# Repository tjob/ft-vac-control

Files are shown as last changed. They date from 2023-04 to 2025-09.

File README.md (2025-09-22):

# Use a Festool Bluetooth remote control with any vacuum

Use the Festool Bluetooth remote with vacuum extractors from other manufacturers.

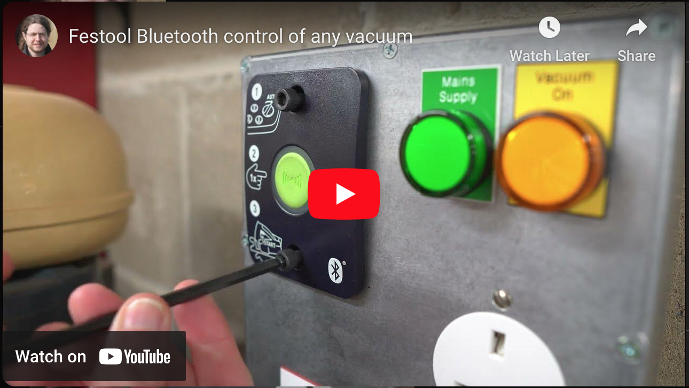
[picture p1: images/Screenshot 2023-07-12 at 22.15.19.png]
Video Demo (https://youtu.be/SCtY6I_2gwY)


The project contains the schematics and PCB layout designed using [KiCad 7](https://www.kicad.org/), and the firmware (written in C) for the [Raspberry Pi Pico](https://www.raspberrypi.com/products/raspberry-pi-pico/) to interface with a [Festool No. 202097 Bluetooth Remote Control add-on](https://www.amazon.co.uk/Festool-202097-Remote-Control-Blue/dp/B0794ZWFLR).

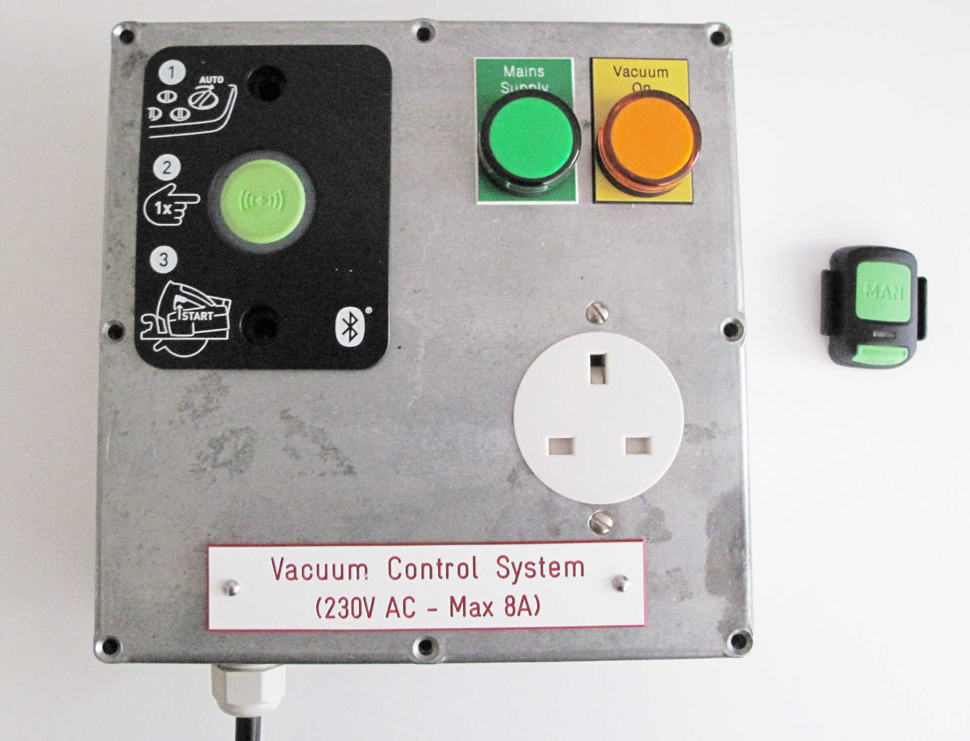
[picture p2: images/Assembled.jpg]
Assembled project


Festool sell an upgrade for their CT26/36/48 vacuum extractors to give remote control using Bluetooth, CT-F I/M-Set. It has two parts: the "CT-F I/M" installs in the extractor and the "CT-F I" is the button that attaches to the end of the vacuum hose. The button then starts and stops the extractor. Paired cordless tools with their Bluetooth-enabled batteries can also control the extractor.

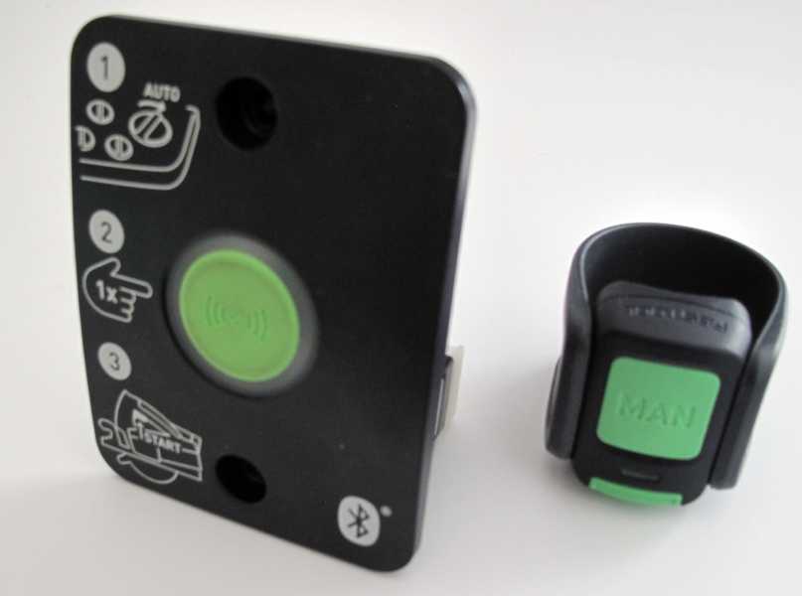
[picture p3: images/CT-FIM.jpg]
Festool's bluetooth kit


But I don't have a CT26/36/48 extractor from Festool, so I wanted to create an adaptor that uses the module and controls a standard power socket to control any device attached. With a custom PCB, a Raspberry Pi Pico, some firmware, a Solid State Relay, and an enclosure I had a working solution.  Along the way I had to reverse-engineer the non-standard serial protocol and try to make sense of the bytes sent.

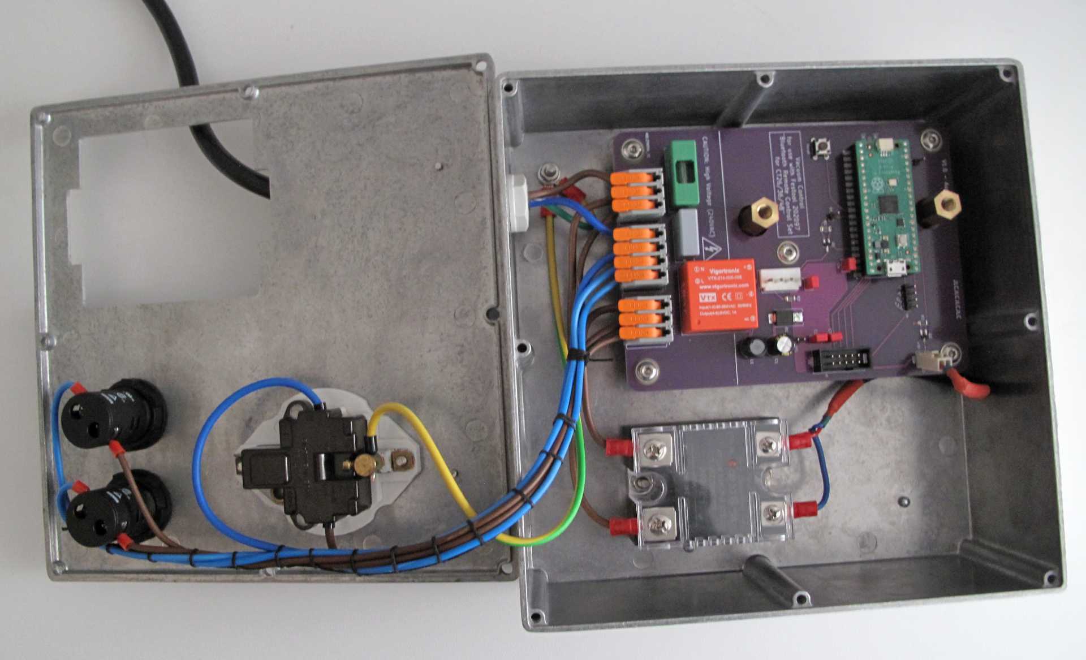
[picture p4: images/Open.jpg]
Inside the box


## Features
 - Allows connecting any vacuum extractor that has a physical switch capable of being always on. A vacuum with an NVR will not work.
 - Works with an unmodified Festool No. 202097 receiver. It's Plug and Play. At a later date if I ever get a CT extractor I wanted to be able to use this module again.
 - Has software safety features: automatically turns off if left on for an extended period. Uses the RP2040's hardware watchdog to shut off the power if the software stops for any reason.
 - Should work with Festool cordless tools with their Bluetooth batteries (untested). 

## How it works
The Festool module has three electrical connections to the host vacuum: two for power and one for data. The data line is serial, probably bidirectional, and uses a form of Manchester encoding. For more details on the serial stream and commands, see the [description of the traces](./software/traces/) captured with a logic analyzer.

Decoded serial steam

The serial data from the receiver feeds the Raspberry Pi Pico via a BSS138 MOSFET as a level shifter. The Pico decodes the Manchester-encoded stream. When the Start/Stop commands are seen the software switches a Solid State Relay controlling mains AC supply to the output socket.

Wanting an excuse to learn KiCad, I designed a custom PCB to host the Pi Pico and a 4-pin 3.96 mm header to plug the CT-F I/M Bluetooth module into. The board contains a 240V switch-mode regulator providing 5V DC power to both the Pico and the CT-F I/M.

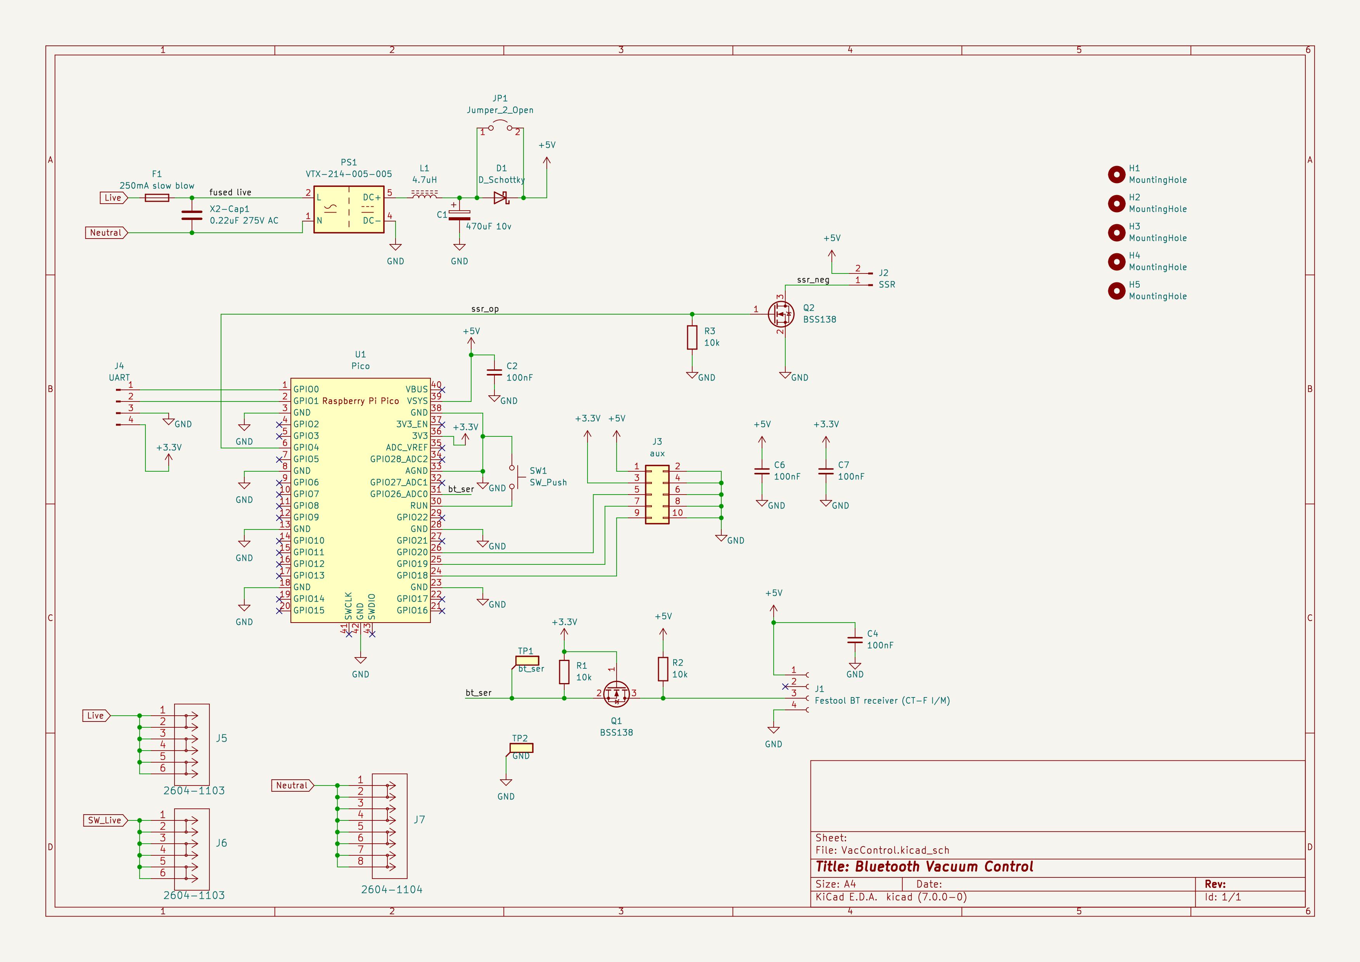
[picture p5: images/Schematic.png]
Circuit schematic diagram


## :zap: Mains voltage electricity can kill! :zap: 

> [!WARNING] 
> This project description is not a guide and does not detail how to assemble a unit safely.  If you are not sure how to build one that is safe and complies with local laws and regulations, DO NOT ATTEMPT TO RECREATE.

## Bill of Materials

Parts on the PCB
| Part | Reference Designator | Description |
| ---- | --- | --- |
| MCU | U1 | Raspberry Pi Pico, [the cheap one](https://thepihut.com/products/raspberry-pi-pico?variant=41925332533443)|
| 5V PCB mount PSU | PS1 | [Vigortronix VTX-214-005-005 5W Miniature SMPS AC-DC Converter 5V Output](https://www.rapidonline.com/vigortronix-vtx-214-005-005-5w-miniature-smps-ac-dc-converter-5v-output-84-2731) |
| Fuse holder | F1 | [5.2x20mm PCB Fuse Holder W/Cover 6.3A 250VAC](https://www.switchelectronics.co.uk/products/5-2x20mm-pcb-fuse-holder-w-cover-6-3a-250vac) |
| PSU protection diode | D1 | Optional, diode to stop power from USB flowing back into the PSU. If not installed, bridge JP2 instead |
| RX data port | J1 | Connects to the Festool receiver module. 4 pin, 3.96mm pitch header with plastic tab cut off - e.g. [JST B4P-VH(LF)(SN)](https://www.rapidonline.com/jst-b4p-vh-lf-sn-4-pole-top-entry-vh-series-p3-96-mm-22-5294) |
| SSR driver header | J2 | 2 way, 2.54mm board-to-wire header for connecting to the input of the SSR |
| Wago 3 way PCB connector | J5, J6 |Wago part number 2604-1103 |
| Wago 4 way PCB connector | J7 | Wago part number 2604-1104 |
| Signal MOSFETs | Q1,  Q2| BSS138, in SOT-23 package |
| 10k Resistors | R1, R2, R3 | SMT 1206 package  |
| 4.7uH | L1 | Inductor, [RLB0913-4R7K](https://uk.farnell.com/bourns/rlb0913-4r7k/inductor-4-7uh-4a-10-radial/dp/2725243) |
| 100nF | C2, C4, C6, C7 | Decoupling capacitors, through-hole, 2.5mm pitch | 
| 470uF 10V | C1 | [Suntan TS13DJ1A471MSB040R 470uf 10V Low Imp Electrolytic Capacitor](https://www.rapidonline.com/suntan-ts13dj1a471msb040r-470uf-10v-low-imp-electrolytic-capacitor-11-3664) |
| X2 Capacitor | X2-Cap1 | [Vishay BFC2-336-20224 220n 275V X2 Suppression Capacitor](https://www.rapidonline.com/vishay-bfc2-336-20224-220n-275v-x2-suppression-capacitor-10-2680)|
| Debug UART | J4 |  Optional (usefully only for firmware development) |
| Test points | TP1, TP2 | Optional, do not populate |
| Aux port | J3 | Optional and currently unused |
| Reset switch | SW1 | Optional (usefully only for firmware development) |

Other mechanical and electrical parts 

| Parts | Count | Description |
| ----- | ----- | --- |
| Enclosure | 1 | 190mm x 190mm x 67mm die-cast aluminum box  |
| Mains plug + inlet cable | 1 | I used a molded plug on a cable cut from an IEC lead |
| Power in strain relief | 1 | Cable Gland M16 10mm - e.g. [50616PA7001SET](https://cpc.farnell.com/hylec/50616pa7001set/nylon-m16-cable-gland-grey/dp/CBBR4095) |
| Output socket | 1 | 13A Circular Panel Mount Socket Outlet, 13A - e.g. [735WHI](https://cpc.farnell.com/mk/735whi/1-gang-outlet-panel-mount/dp/PL00703)
| Green indicator | 1 | Panel mount, 22.5mm, 220-240v, to show if the incoming power is on - e.g. [LEDTECGREEN230VAC](https://www.rapidonline.com/techna-ledtecgreen230vac-led-pilot-light-green-220-240vac-28-5357) |
| Yellow indicator | 1 | Panel mount, 22.5mm, 220-240v, LED lamp, to show if the vacuum power is on - e.g. [LEDTECYELLOW230VAC](https://www.rapidonline.com/techna-ledtecyellow230vac-led-pilot-light-yellow-amber-220-240vac-28-5369) |
|PCB standoffs | 5 | M4 - length dependent on the enclosure used |
| M6 x 35mm cap screws | 2 | Black, for securing the Festool receiver module |
| Custom M6 standoffs | 2 | To receive the M6 screws from the Festool receiver module. Length depends on the enclosure used, 39.1mm was correct for me |
| PCB screws | 5 | M4 x 8mm |
| SSR | 1 | Random on Solid State Relay, must be switchable by 5V DC - e.g. [i-Autoc Panel Mount Solid State Relay, 25 A Max. Load, 280V AC](https://uk.rs-online.com/web/p/solid-state-relays/1640576) |
| SSR cover | 1 | [i-Autoc Kudom KPC-0A Solid State Relay Accessory Protective Cover Single Phase](https://www.rapidonline.com/i-autoc-kudom-kpc-0a-solid-state-relay-accessory-protective-cover-single-phase-60-1586) |
| SSR thermal pad | 1 |[i-Autoc Kudom KTP-0A Solid State Relay Accessory Thermal Pad KSI/KSJ](https://www.rapidonline.com/i-autoc-kudom-ktp-0a-solid-state-relay-accessory-thermal-pad-ksi-ksj-60-1587) |
| Mains wiring loom | Assorted | Line, Neutral, Earth (CPC), sided appropriately for your max load. I used stranded 2.5mm<sup>2</sup> |
| Bits 'n' Bobs | Assorted | Hardware to attach standoffs to enclosure and to mount the SSR, earth bonding nuts and bolds, and crimp eyelets and spade connectors |

## License
The software, schematic designs and PCB layout contained in this repository are released under the MIT license.

## Credits
I got the pinout for the Bluetooth receiver from YouTube channel "My Project Box". His video ["Festool Bluetooth Hack / Mod works with any dust extractor!"](https://www.youtube.com/watch?v=EyrakKOR5tI) shows a very neat solution with a different approach; avoiding any software.

On Github, user gilbertf published [libft](https://github.com/gilbertf/libft) capable of both sending and receiving. It's not used by this project but his encoder appears to send the same bytes my decoder expects, which gave me some confidence that the implementation here is somewhat interoperable.

I used the Pi Pico KiCAD symbol and footprint from [ncarandini/KiCad-RP-Pico](https://github.com/ncarandini/KiCad-RP-Pico)

## Other projects inspired by this one
This project helped [Loriowar](https://github.com/Loriowar) create a [Festool receiver handler](https://github.com/Loriowar/festool_ct-f_im_handler) for Arduino.

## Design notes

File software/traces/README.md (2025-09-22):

# Serial signal traces

These traces (.sr files) capture the output signal of the Festool CT-F I/M Bluetooth module when not connected to a CT vacuum extractor.  They can be viewed using [Pulseview](https://sigrok.org/wiki/PulseView) from the sigrok project.

## Power on reset [(Startup.sr)](Startup.sr)
Approximately 590 ms after power on, the Bluetooth module sends a single 1 byte message of `0x1d` to the extractor.  Its function is unknown.

## Manual remote on [(On.sr)](On.sr)
When the Bluetooth module receives the first (and all other odd numbered) press of the manual remote (CT-F I) button the module sends 3 separate messages to the extractor. Each is two bytes long.

```
Message 1:
0x0117 (2 bytes)  // Turn extractor on command
[Delay of ~284 ms]

Message 2:
0xff23 (2 bytes)  // Extractor at full speed?
[Delay of ~387 ms]

Message 3:
0x0117 (2 bytes)  // Repeated turn on command
```

Assumptions: The first and last messages are the ON command, not clear why it's repeated (maybe because the extractor did not reply?).  The middle message sets the extractor speed.

## Manual remote off [(Off.sr)](Off.sr)

For the second press of the manual (CT-F I) remote, and all subsequent even numbered presses, the Bluetooth module sends 4 separate messages to the extractor.

```
Message 1:
0xac17   (2 bytes)  // Turn extractor off command
[Delay of ~11.7 ms]

Message 2:
0x000123 (3 bytes)  // Reduce speed, with rate?
[Delay of ~277 ms]

Message 3:
0x00a0   (2 bytes)  // Unknown?
[Delay of ~689 ms]

Message 4:
0x0023   (2 bytes)  // Reduce speed to zero?
```

Assumptions: The first message is the OFF command. The second and fourth messages are to reduce the speed to zero. The function of the third message is not obvious.

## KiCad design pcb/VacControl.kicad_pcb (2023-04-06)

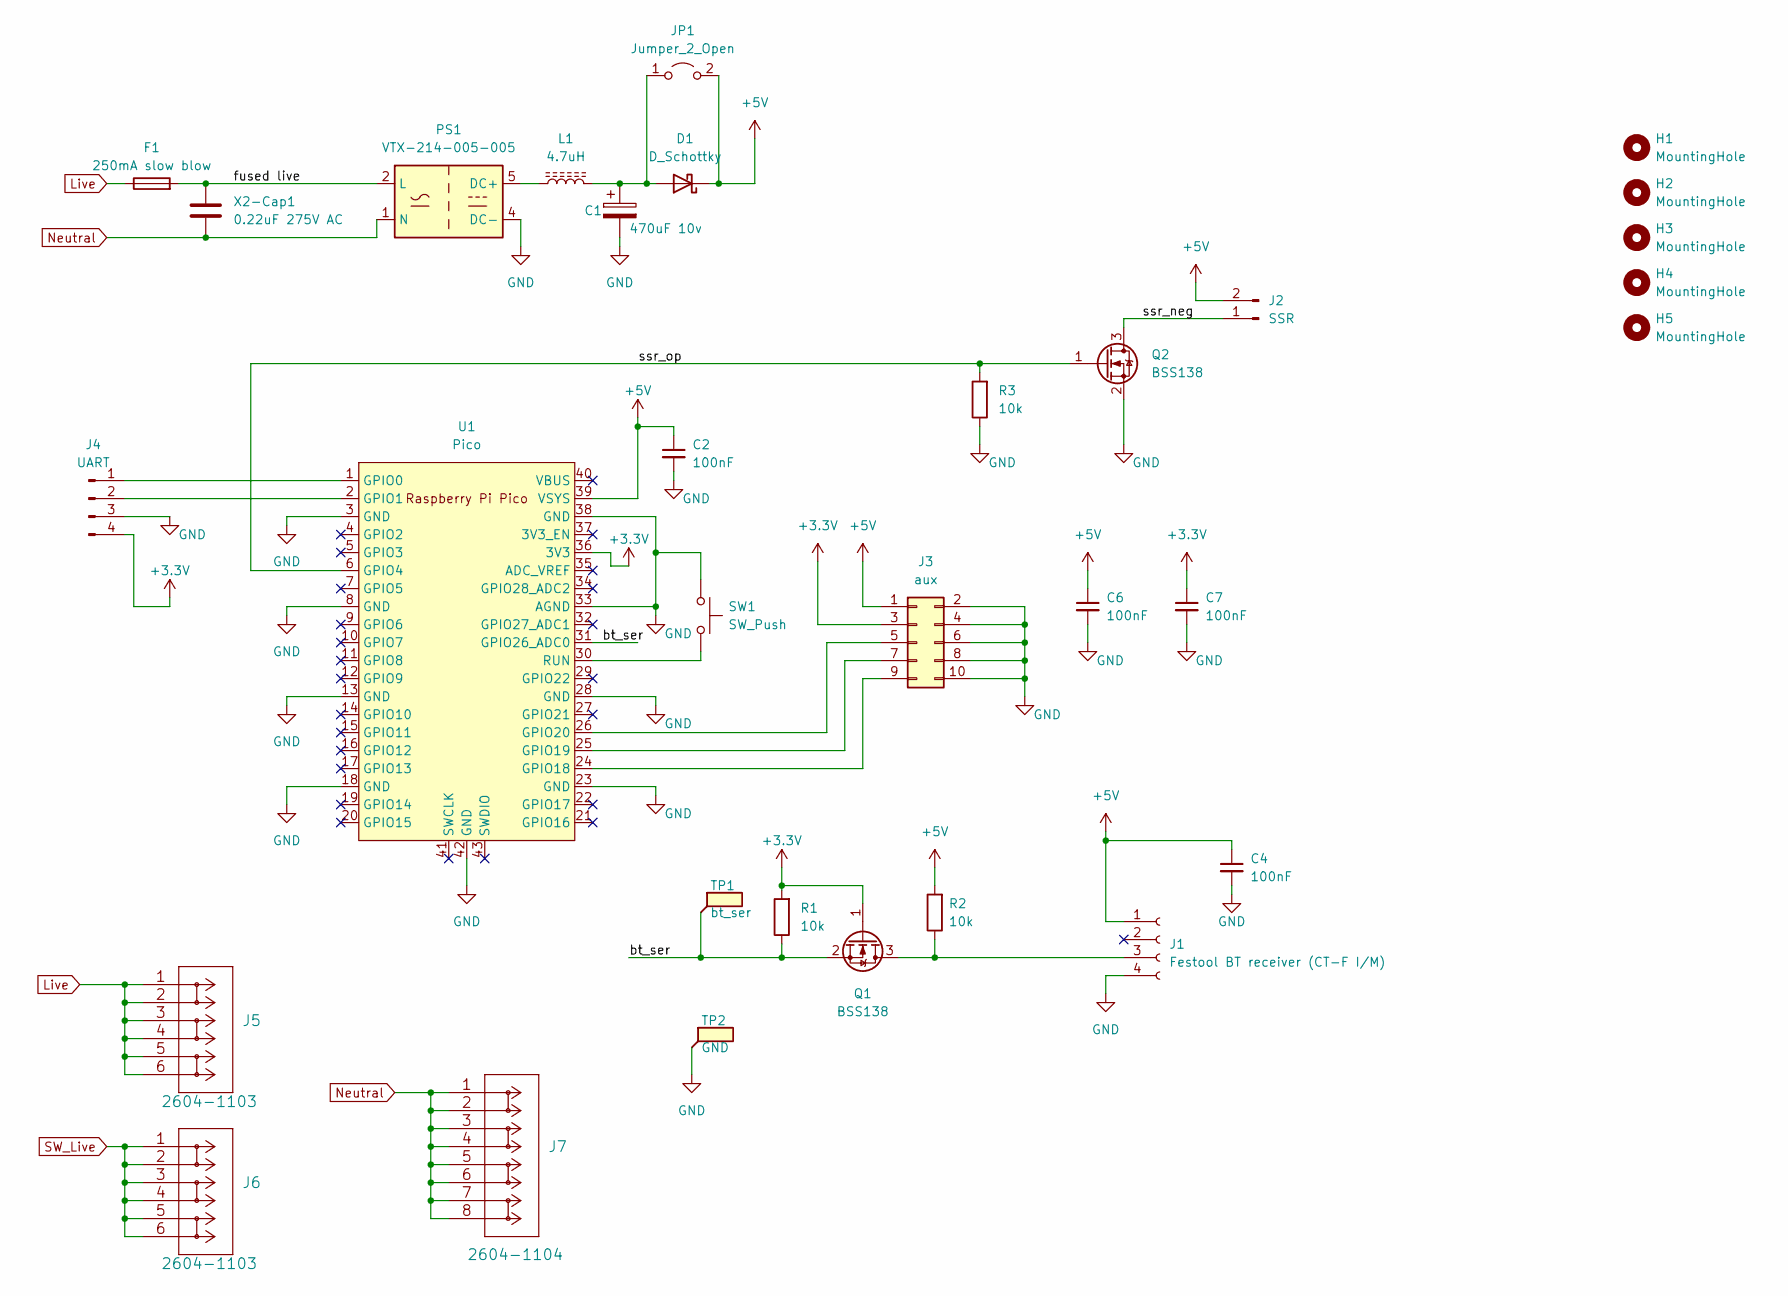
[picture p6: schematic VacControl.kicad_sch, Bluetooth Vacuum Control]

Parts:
C1: 470uF 10v; CP_Radial_D8.0mm_P3.50mm
C2, C4, C6, C7: 100nF; C_Rect_L4.6mm_W3.0mm_P2.50mm_MKS02_FKP02
D1: D_Schottky; D_SMC_Handsoldering
F1: 250mA slow blow; Fuseholder_Cylinder-5x20mm_Stelvio-Kontek_PTF78_Horizontal_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
H1, H2, H3, H4, H5: MountingHole; MountingHole_4.3mm_M4
J1: Festool BT receiver (CT-F I/M); BT receiver
J2: SSR; Molex_KK-254_AE-6410-02A_1x02_P2.54mm_Vertical
J3: aux; IDC-Header_2x05_P2.54mm_Vertical
J4: UART; PinSocket_1x04_P2.54mm_Vertical
J5, J6: 2604-1103
J7: 2604-1104
JP1: Jumper_2_Open; TestPoint_2Pads_Pitch2.54mm_Drill0.8mm
L1: 4.7uH; L_Radial_D7.8mm_P5.00mm_Fastron_07HCP
PS1: VTX-214-005-005; Converter_ACDC_Vigortronix_VTX-214-005-0xx_THT
Q1, Q2: BSS138; SOT-23_Handsoldering
R1, R2, R3: 10k; R_1206_3216Metric_Pad1.30x1.75mm_HandSolder
SW1: SW_Push; SW_PUSH_6mm_H4.3mm
TP1: bt_ser; Pin_D0.9mm_L10.0mm_W2.4mm_FlatFork
TP2: GND; Pin_D0.9mm_L10.0mm_W2.4mm_FlatFork
U1: Pico; RPi_Pico_SMD_TH
X2-Cap1: 0.22uF 275V AC; C_Rect_L18.0mm_W7.0mm_P15.00mm_FKS3_FKP3

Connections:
+3.3V: C7.1, J3.3, J4.4, Q1.1 (G), R1.2, U1.36 (3V3)
+5V: C2.1, C4.1, C6.1, D1.1 (K), J1.1, J2.2, J3.1, JP1.2 (B), R2.2, U1.39 (VSYS)
/bt_ser: Q1.2 (S), R1.1, TP1.1, U1.31 (GPIO26_ADC0)
/fused live: F1.2, PS1.2 (L), X2-Cap1.1
/ssr_neg: J2.1, Q2.3 (D)
/ssr_op: Q2.1 (G), R3.2, U1.6 (GPIO4)
GND: C1.2, C2.2, C4.2, C6.2, C7.2, J1.4, J3.2, J3.4, J3.6, J3.8, J3.10, J4.3, PS1.4 (DC-), Q2.2 (S), R3.1, SW1.1, TP2.1, U1.3 (GND), U1.8 (GND), U1.13 (GND), U1.18 (GND), U1.23 (GND), U1.28 (GND), U1.33 (AGND), U1.38 (GND), U1.42 (GND)
Live: F1.1, J5.1, J5.2, J5.3, J5.4, J5.5, J5.6
unnamed: C1.1, D1.2 (A), JP1.1 (A), L1.2
unnamed: J1.3, Q1.3 (D), R2.1
unnamed: J3.5, U1.26 (GPIO20)
unnamed: J3.7, U1.25 (GPIO19)
unnamed: J3.9, U1.24 (GPIO18)
unnamed: J4.1, U1.1 (GPIO0)
unnamed: J4.2, U1.2 (GPIO1)
unnamed: L1.1, PS1.5 (DC+)
unnamed: SW1.2, U1.30 (RUN)
Neutral: J7.1, J7.2, J7.3, J7.4, J7.5, J7.6, J7.7, J7.8, PS1.1 (N), X2-Cap1.2
SW_Live: J6.1, J6.2, J6.3, J6.4, J6.5, J6.6

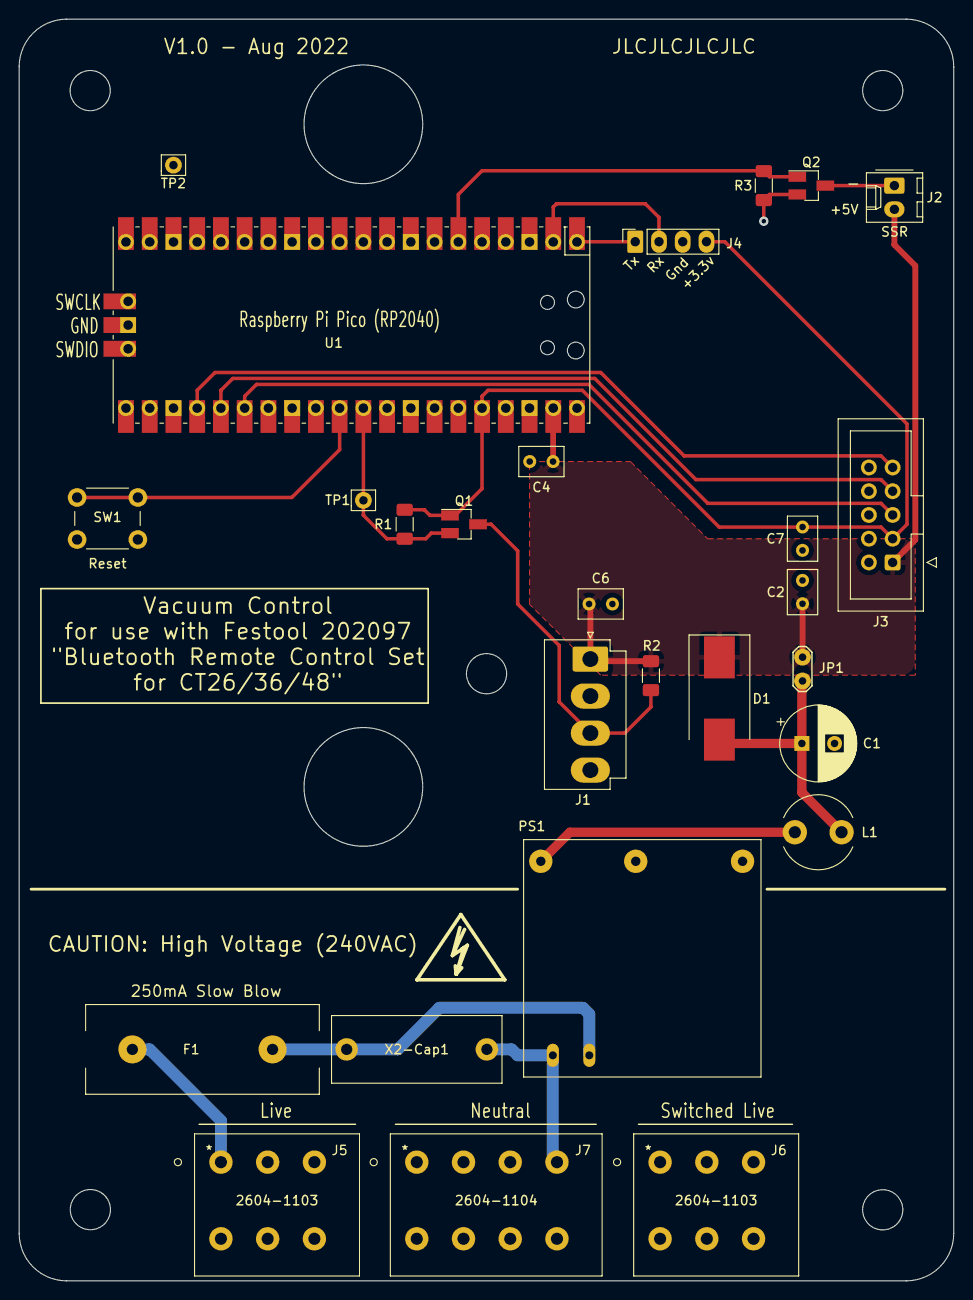
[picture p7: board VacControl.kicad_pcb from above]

Board: 2 copper layers, 100.0 x 135.0 mm, 33 parts (0 on the bottom side), 19 nets.

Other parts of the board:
CAUTION: High Voltage (240VAC): Warning; Symbol_HighVoltage_Type2_CopperTop_VerySmall

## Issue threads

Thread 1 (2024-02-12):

Mention Adruino alternative in the Readme

Loriowar, 2024-02-12:
Hi! Thanks for your project. It helps me to build my own implementation of [Festool receiver handler](https://github.com/Loriowar/festool_ct-f_im_handler). It's built on Arduino Nano and for some people might be even simpler in the implementation in compare with Pico. If you decide this is worth you can add the mention of the [Arduino alternative](https://github.com/Loriowar/festool_ct-f_im_handler) in the Readme.

tjob, 2024-12-02:
Glad you found this helpful,  I added a link to your repo.

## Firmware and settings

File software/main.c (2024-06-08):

/**
 * @file main.c
 * @author tjob
 * @brief Use a Raspberry Pi Pico and a "Festool 202097 CT-F I/M" to control any vacuum extractor.
 * @version 0.1
 * @date 2023-04-02
 * 
 * @copyright Copyright (c) 2023
 * 
 * Uses one GPIO pin, as an input, to read the serial data line from the 
 * Festool Bluetooth receiver. Another GPIO pin, as an output, is used to turn 
 * on/off a relay controlling power to the vacuum extractor.
 */
#include "pico/stdlib.h"
#include "hardware/watchdog.h"
#include <stdio.h>
#include <time.h>
#include "decoder.h"

int main() {
    const uint32_t AUTO_OFF_AFTER = 20*60*1000; ///< Automatically turn off the vacuum if left on for more than 20 minutes.
    const uint FTBT_PIN = 26;   ///< GPIO pin connected to the Festool CT-F I/M Bluetooth receiver module. 
    const uint SSR_PIN = 4;     ///< GPIO pin connected to the Solid State Relay

    decoder_t decoder = {0};            ///< The one and only decoder
    absolute_time_t autoOffTime = {0};  ///< Used to track the absolute time we should automatically turn off if left on.
    uint32_t ticksObserved = 0;         ///< Used to check the decoder is still ticking for the hardware watchdog.
    msg_t message = {0};                ///< Holds a message de-queued from the decoder's FIFO. 

    stdio_init_all();

    if (watchdog_caused_reboot()) {
        printf("Rebooted by watchdog!\n");
    }

    // Setup onboard LED on the Pi Pico as an output. 
    gpio_init(PICO_DEFAULT_LED_PIN);
    gpio_set_dir(PICO_DEFAULT_LED_PIN, GPIO_OUT);

    // Setup the input pin to read the serial line-code from the bluetooth adaptor.
    gpio_init(FTBT_PIN);
    gpio_set_dir(FTBT_PIN, GPIO_IN);

    // Setup the output pin to drive the Solid State Relay controlling the power to the vacuum. 
    gpio_init(SSR_PIN);
    gpio_set_dir(SSR_PIN, GPIO_OUT);
    gpio_put(SSR_PIN, false);   // Default relay output to off at startup.

    // Setup the decoder
    initDecoder(&decoder, FTBT_PIN);
    startDecoder(&decoder);

    // Enable the HW watchdog timer. Needs servicing at least ever 300ms to avoid a hardware reset.
    watchdog_enable(300, true);

    // Main loop.  Never ends, only way out is power down or watchdog reset.
    while (true) {
        // Blink the onboard led as a sign of life.
        gpio_put(PICO_DEFAULT_LED_PIN, time_us_32() & (1 << 19));

        // Delay long enough for the Decoder's timer to have ran at least once
        sleep_ms(10);

        // Only service the watchdog if both the decoder timer and this main loop
        // are running.  If either stops, for any reason, watchdog will reset the 
        // hardware for us.
        if (ticksObserved != decoder.totalTicks) {
            watchdog_update();
            ticksObserved = decoder.totalTicks;
        }

        // Consume all messages from the decoder waiting in the fifo.
        while (queue_try_remove(&decoder.messageFIFO, &message)) {
            // Print the message
            printf("0x%08lx  %d\n", message.data, message.bitsRecieved);

            // Is it a start command?
            if (message.data == (CMD_POWER | CMD_ON)) {
                // Turn on the relay output
                gpio_put(SSR_PIN, true);

                // Safety feature: Calculate the time we should turn off automatically if we need to.
                autoOffTime = make_timeout_time_ms(AUTO_OFF_AFTER);
            }

            // Is it a stop command?
            if (message.data == (CMD_POWER | CMD_OFF)) {
                // Turn off the relay output
                gpio_put(SSR_PIN, false);
            }

            // All other commands are ignored for now.
        }

        // Safety feature: Automatically turn off the vacuum if it's been on too long. 
        if (AUTO_OFF_AFTER && time_reached(autoOffTime)) {
            gpio_put(SSR_PIN, false);
        }
    }

    // Should never get here! Halt.
    stopDecoder(&decoder);
    while (true) {}
    
    return 0;
}

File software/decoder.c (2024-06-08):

/**
 * @file decoder.c
 * @author tjob
 * @brief Decoder serial stream coming from Festool No. 202097 CT-F I/M
 * @version 0.1
 * @date 2023-04-02
 * 
 * @copyright Copyright (c) 2023
 * 
 * The Festool 202097 CT-F I/M Bluetooth add-on for CT26/36/48 vacuum extractors 
 * has 3 electrical connections to the host vacuum; GND, +5V, and Data. The 
 * data line is used for serial communication and runs at approximately 1 kHz. 
 * The Bluetooth receiver encodes bits onto the data line using a form of 
 * Manchester encoding. Line transitions from high to low represent a 1, and 
 * transitions from low to high represent a 0. The line idles high when nothing 
 * is being sent. Messages start with a "break", pulling the line low for 
 * approximately 2 bit periods (2 ms), followed by a "mark" of 1 ms.  There is 
 * a start bit, always 0, followed by several bytes of data. Bytes are sent 
 * least significant bit first.
 * 
 * This decoder receives and decodes the incoming serial stream into messages
 * up to 32bits in length (4 bytes). We define a message to be the bit sequence
 * after the start bit until the line goes idle again. All messages seen so far
 * are an integer number of bytes long. A single press of the manual remote 
 * button results in multiple messages being sent, with a relatively long delay 
 * (100's of ms) between then.
 * 
 * Note: While this decoder works, it's based on observations of one receiver 
 * and one manual remote button. It has not been tested with any of the Festool 
 * cordless Bluetooth battery tools. It is suspected that the serial interface 
 * is bi-directional, allowing the vacuum extractor to respond to the commands. 
 * This implementation is receive only.
 * 
 * Theory of operation:
 * on_16x_timer() runs, ticks from a hardware timer, at approximately 16 times 
 * bit rate. Based on the current state, how long we have been in that state, and
 * how long it's been since the last edge was seen we can decode the signal.
 * The timer is free running but the state machine within synchronizes to the
 * edges seen on the serial input. This takes care of any drift. 
 * 
 * To decode the Manchester signal we sample the input twice per bit. Each 
 * sample gives us a "Chirp", and two of those are needed to decode a bit.
 * Chirps are sampled at 1/4 of a bit period after an edge and again at 3/4 of 
 * a bit period if the next edge is not seen yet. Pairs of chirps give us 
 * decoded bits: 1,0 = 1 and 0,1 = 0.  
 */
#include "pico/stdlib.h"
#include "decoder.h"

/**
 * @brief Decode Manchester chirp pairs.  10 = 0 and 01 = 1
 * 
 * @param upper The upper, first, chirp
 * @param lower The lower, second, chirp
 * @return int 1 if bit is true, 0 for false and -1 for an invalid chirp pair
 */
int manPairToBit(bool upper, bool lower)
{
    if (upper && !lower)
        return 0;

    if (!upper && lower)
        return 1;

    return -1;
}

/**
 * @brief Clear any previously read bits, resets counters ready for the start of the next message.
 * 
 * @param dec Pointer to a decoder structure.
 */
void clearBits(decoder_t *dec)
{
    dec->message.data=0;
    dec->rxMask = 1;
    dec->message.bitsRecieved = 0;
}

/**
 * @brief Add the complete message to the fifo for consumption in the main loop.
 * 
 * @param dec Pointer to a decoder structure.
 */
void processBits(decoder_t *dec)
{
    queue_try_add(&dec->messageFIFO, &dec->message);
    clearBits(dec);
}

/**
 * @brief Set the State of the decoder
 * 
 * @param dec Pointer to a decoder structure.
 * @param newState The new state the decoder is transitioning too.
 */
void setState(decoder_t *dec, uint newState)
{
    dec->state = newState;
    dec->ticksInState = 0;  // Count since last state change.
}

/**
 * @brief Runs on a timer at 16x the speed of bit (1 ms), so every 62.5 us (i.e. at 16 kHz)
 * 
 * @param rt Pointer to a repeating timer structure.
 * @return Always returns true so the timer continues to tick. 
 * 
 * This is the main decoding state machine.
 */
bool __not_in_flash_func(on_16x_timer)(repeating_timer_t *rt)
{
    decoder_t *dec = (decoder_t*)rt->user_data;
    const bool current = gpio_get(dec->inputPin);
    bool edgeDetected = false;

    // Has there been an edge since the last tick?
    if (dec->last != current) {
        dec->last = current;
        edgeDetected = true;
        dec->ticksSinceEdge = 0;
    }

    switch (dec->state) {
        // The serial line idles high between messages.
        // In this state we are waiting for the line to fall, signaling the 
        // start of the "break" before the message content.
        case IDLE:
            if (current == 0) {
                setState(dec, BREAK);
            }
            break;

        // In the break state, the serial line is driven low for 2 ms. i.e
        // the length of 2 bits.
        case BREAK:
            if (current == 1) {
                if ((dec->ticksInState < (TICKS_PER_BIT * 2 - TICKS_PER_QBIT)) ||
                    (dec->ticksInState > (TICKS_PER_BIT * 2 + TICKS_PER_QBIT))) {
                    setState(dec, ERROR);
                } else {
                    setState(dec, MAB);
                }
            }
            break;

        // The Mark After Break (MAB), the line is drive high before 
        // transmission of the start bit.
        case MAB:
            if (dec->ticksInState == TICKS_PER_3QBITS) {
                // Read the first half (upper chirp) of the start bit
                // and save it for the next half
                dec->upperChirp = current;
            }

            if (edgeDetected) {
               setState(dec, dec->ticksInState < TICKS_PER_3QBITS ? ERROR : STARTBIT);
            }
            break;

        // Receive the start bit, it's always 0.
        case STARTBIT:
            if (dec->ticksSinceEdge == TICKS_PER_QBIT) {
                // This is where we would sample second half (lower chirp) of start bit, it will be zero; no need to decode it.
                
                // Setup for reading the message 
                clearBits(dec);

                // Now wait to read the first half bit (chirp) of the message.
                setState(dec, UPPERCHIRP);
            } 
            break;

        // Bits are sent in two parts, chirps, this state reads the second 
        // chirp of a bit. As the lower chirp comes after the upper chirp, at 
        // the end of this state we have a new bit.
        // 
        // When receiving the message content the state machine toggles back
        // and forth between the LOWERCHIRP and UPPERCHIRP states.
        case LOWERCHIRP:
            if (dec->ticksSinceEdge == TICKS_PER_QBIT || dec->ticksSinceEdge == TICKS_PER_3QBITS) {
                // Can now sample the second chirp of the current bit to get a full bit.
                int FullBit = manPairToBit(dec->upperChirp, current);
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

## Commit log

2023-04-01 - Specify the GPIO pin when initilizing the decoder. - It's chirp not chip.
2023-04-02 Bug fixes and start of safety. - Building up recived message was broken due to bad boolan logic. - Automaticaly turn off vacuum if left on for longer than 1 hour.
    [decoder.c, main.c]
2023-04-04 More documentation and trace files used to derive the decoder.
2023-04-05 More details on the traces and added pulse view workspaces to keep the timing decoders.
2023-04-06 KiCad 7 Schematic and PCB files
    [VacControl.kicad_sch]
2023-04-06 Add missing PCB file
    [VacControl.kicad_pcb]
2023-04-07 Added referance image of the schematics and a license section to the readme
2024-06-08 Cleanup main loop - Shorten the auto off duration. - Simplify the led proof-of-life blinker. - Reduce the latancy when a message is received over Blue Tooth.
    [main.c]
2024-12-02 Added BOM and link to similar project
2026-09-12 Bump Pico SDK submodule 1.5.0 -> 2.3.0

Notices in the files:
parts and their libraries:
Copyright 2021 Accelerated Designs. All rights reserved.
